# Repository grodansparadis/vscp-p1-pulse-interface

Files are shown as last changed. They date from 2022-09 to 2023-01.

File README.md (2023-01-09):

# vscp-p1-HAN-interface 

HAN P1 interface for smart meters to serial TTL. Should work with

| Meters |
| ------  |
| Sagemcom T211 / Ellevio & Skånska Energi |
| Landis+Gyr E360 |
| Itron A300 / Borås Elnät |
| S34U18 (Sanxing SX631) / Vattenfall |
| KAIFA MA304H4**E** / Nacka Energi (Not **D** version which is modbus) |
| KAIFA CL109 / Öresundskraft |
| Kamstrup w/ HAN module / Trollhättan Energi |
| and more. |

There is a description [here](https://grodansparadis.com/wordpress/?p=5039) about my setup. 

The PCB, [assembled](https://frogshop.se/product/kort-for-han-p1-ttl-serieinterface-monterat/?v=f003c44deab6) or [bare](https://frogshop.se/product/kort-for-han-p1-ttl-serieinterface-omonterat/?v=f003c44deab6), can be bought from https://frogshop.se/  

Bare PCB or mounted PCB is available from THE VSCP shop.

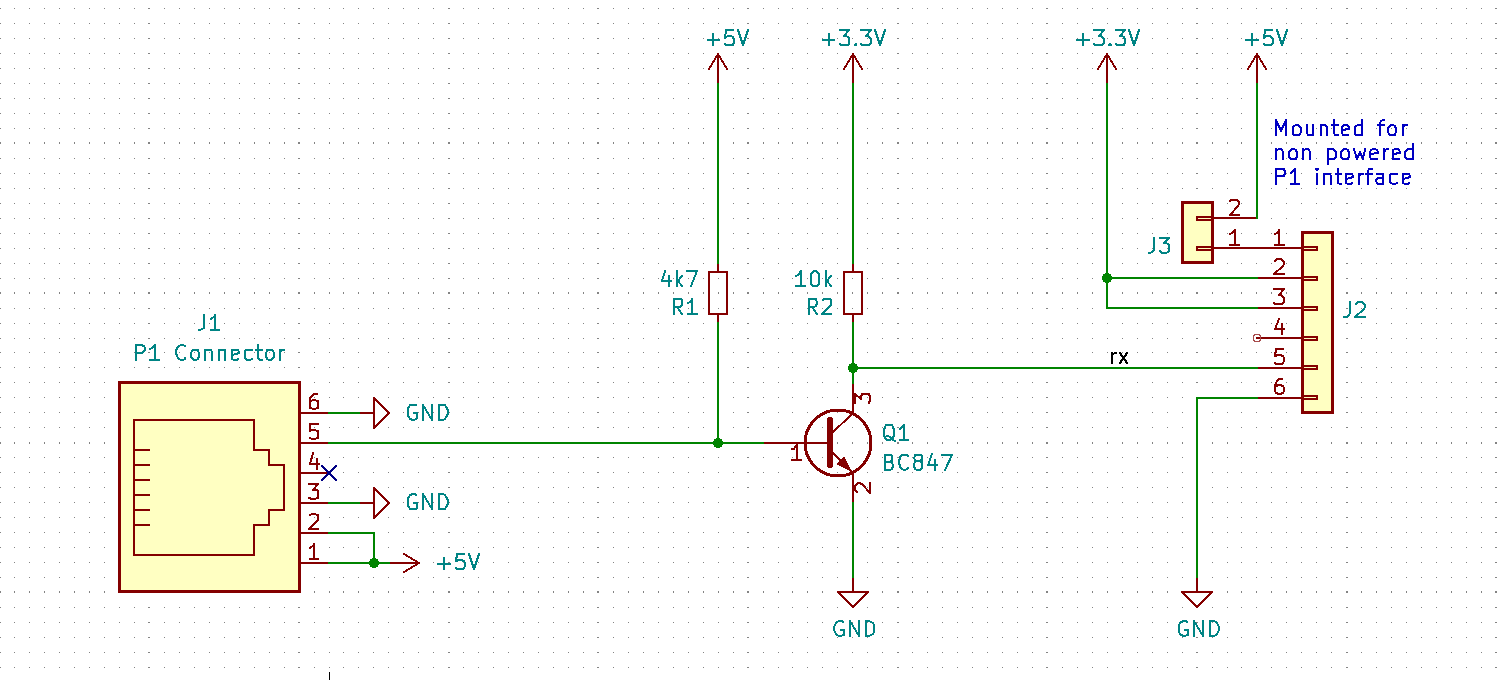
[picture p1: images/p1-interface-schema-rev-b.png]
Schema rev A


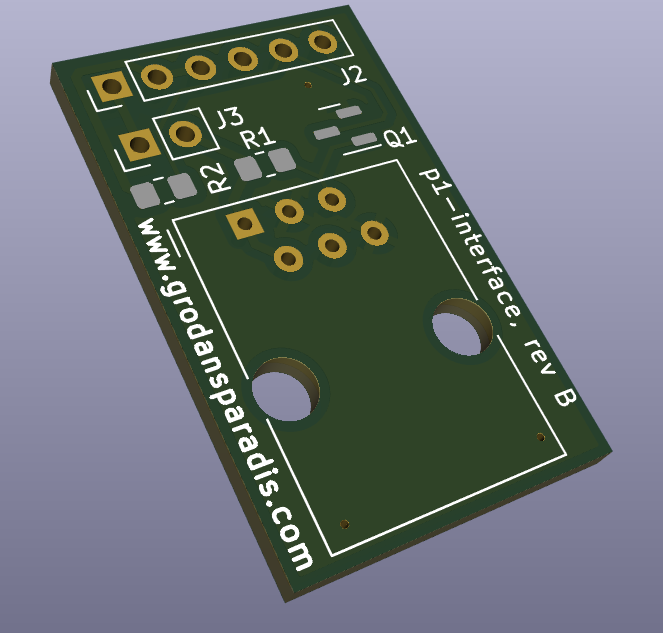
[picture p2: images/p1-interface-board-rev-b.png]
PCB P1 Interface card P1 Interface Card


Interface card for P1 based smartmeter to TTL serial interface.  

## BOM

| Component | Description |
| --- | --- |
| R1 | Resistor 4.7K 0805 |
| R2 | Resistor 10K 0805 |
| T1 | NPM Transistor BC847 |
| J1 | RJ11 Modular connector (Amphenol 54601 or similar) |
| J2 | 6-pin pinheader 2.54 pitch |
| J3 | 2-pin pinheader 2.54 pitch |

## J3 

Strap pins t use if the HAN interface does not provide power by itself.

## J2 Connections

| Pin | Description |
| --- | --- |
| 1 | +5V |
| 2 | +3.3V or 5V * |
| 3 | +3.3V or 5V * |
| 4 | Not Connected |
| 5 | RX (Received data TTL level) |
| 6 | GND |

* Use same power on 2/3 as the serial interface the unit is connected to.

## Connecting 

To connect the interface to a HAN P1 port a serial TTL interface is needed. We describe using an [USB to serial adapter](https://frogshop.se/product/usb-ttl-serial-adapter/?v=f003c44deab6) here but an Arduino or ESP8266/32 or similar can also be used.

First connect the interface to the serial adapter

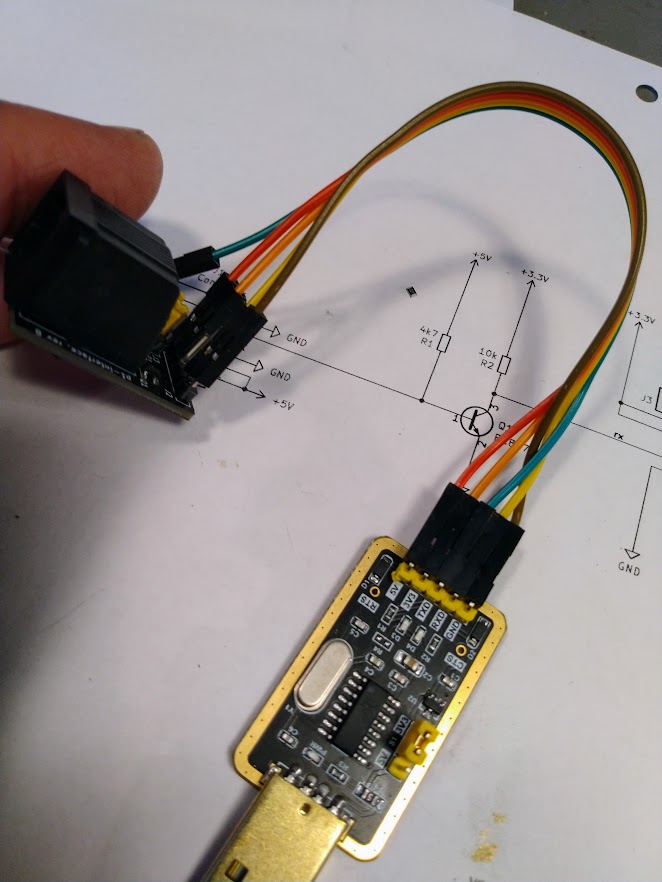
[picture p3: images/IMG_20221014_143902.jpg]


| Interface | TTL adapter |
| --- | --- |
| 1 | +5V |
| 2 | 3.3V |
| 3 | Not connected or 3.3V |
| 4 | Mot connected |
| 5 | RX |
| 6 | GND |

The following two pictures mau be clearer

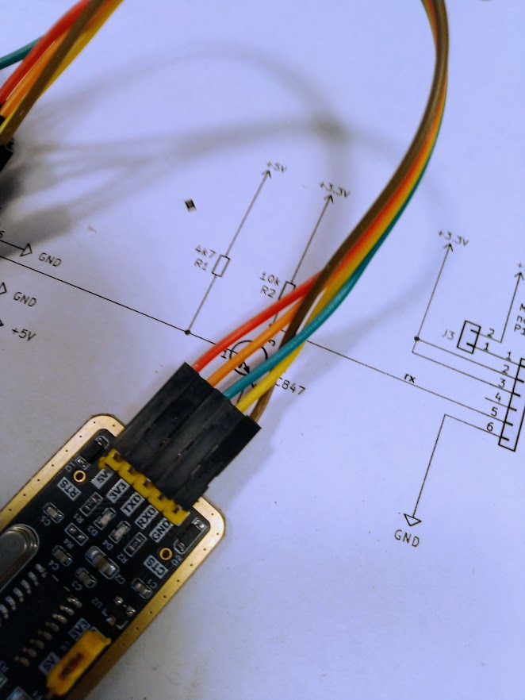
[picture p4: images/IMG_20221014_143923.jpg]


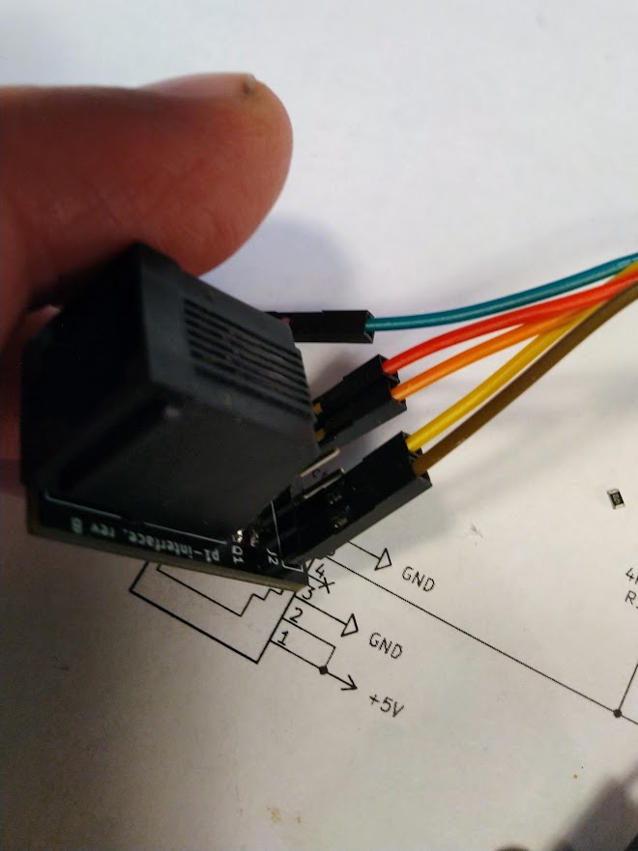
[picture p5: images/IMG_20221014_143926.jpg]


Now draw a standard six leads RJ12 cable from the HAN port of the meter and connect it to the interface. 

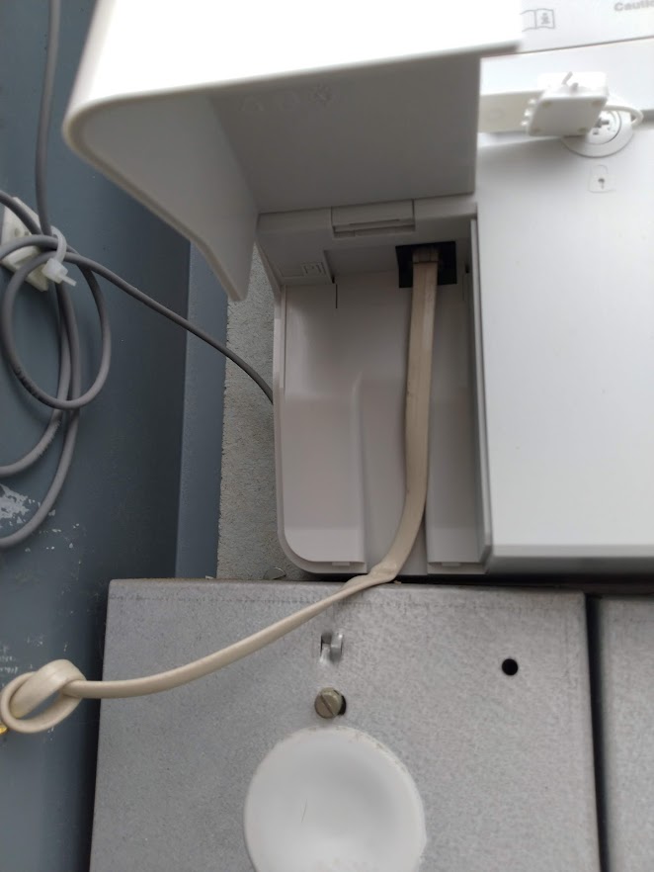
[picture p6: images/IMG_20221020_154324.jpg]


The cable should have the same colors on both connectors (straight cable). Like this

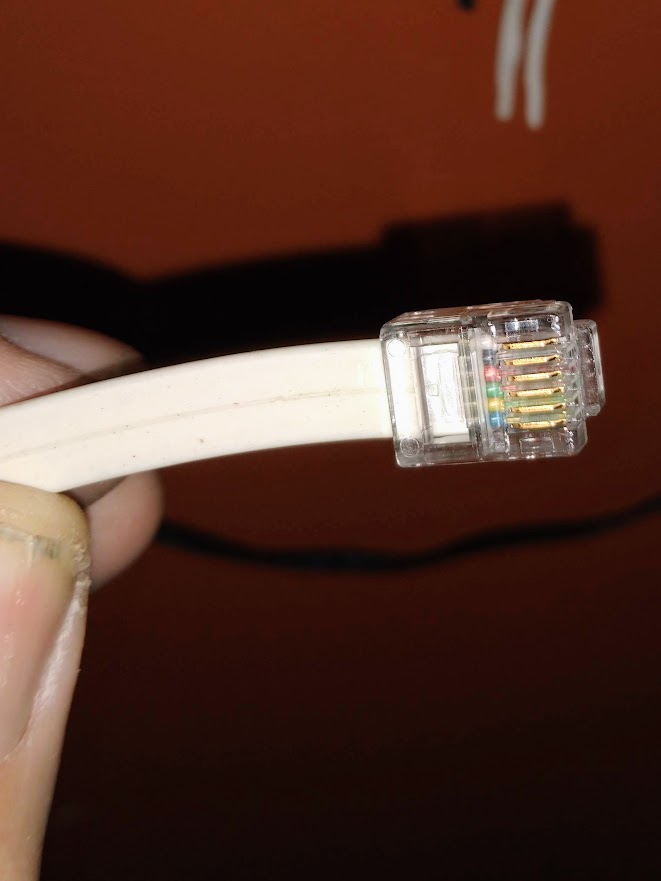
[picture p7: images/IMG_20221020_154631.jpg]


It is OK to use a cable of a few meters. At least if you are in an environment without to much electric disturbance.

Now connect the TTL USB adapter to the serial port. The blue LED should light up on the USB TTL serial adapter. 

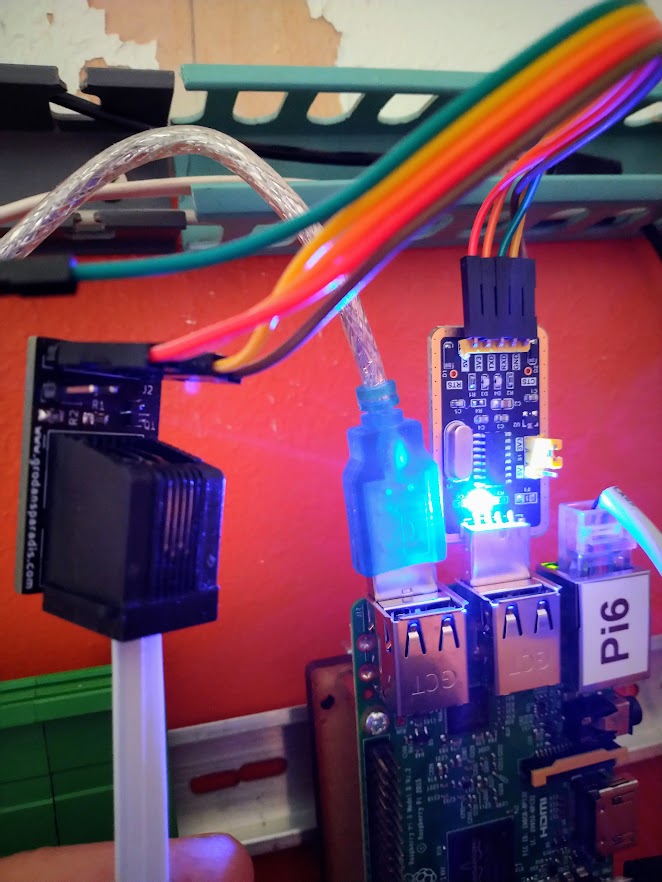
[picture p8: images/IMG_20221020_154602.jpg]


If everything is correct the red RX LED will light up every ten seconds to show that data is received.

Now you are ready to go. More info is [here](https://grodansparadis.com/wordpress/?p=5039) on how to proceed.

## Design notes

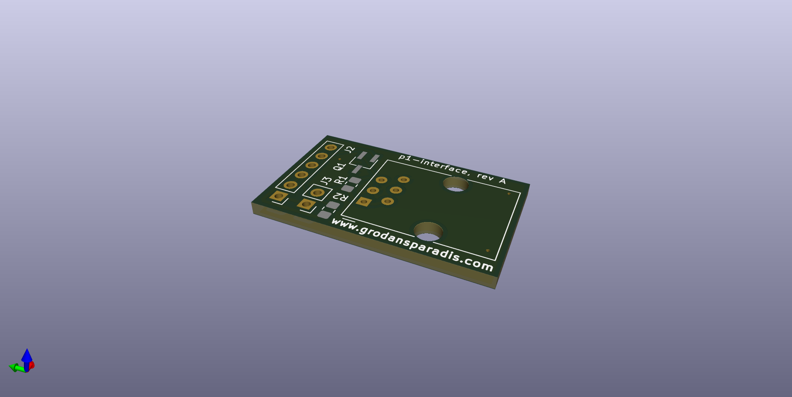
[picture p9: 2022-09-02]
images/p1-interface.png

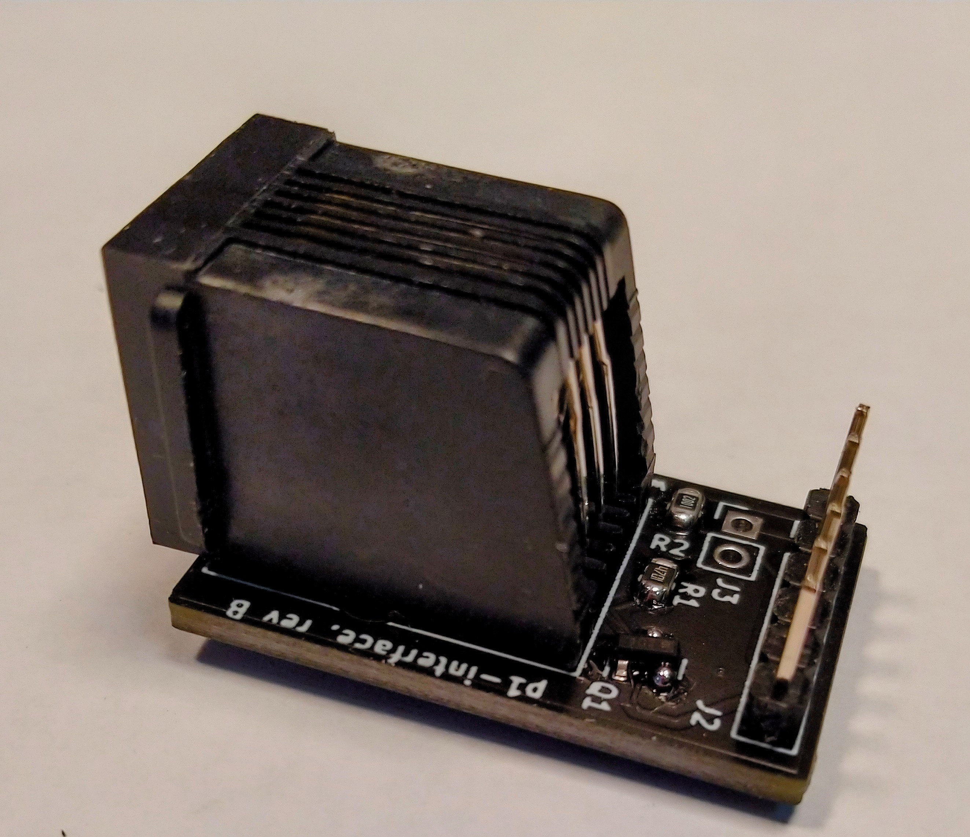
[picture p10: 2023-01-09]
images/IMG_20221020_165559~2.jpg

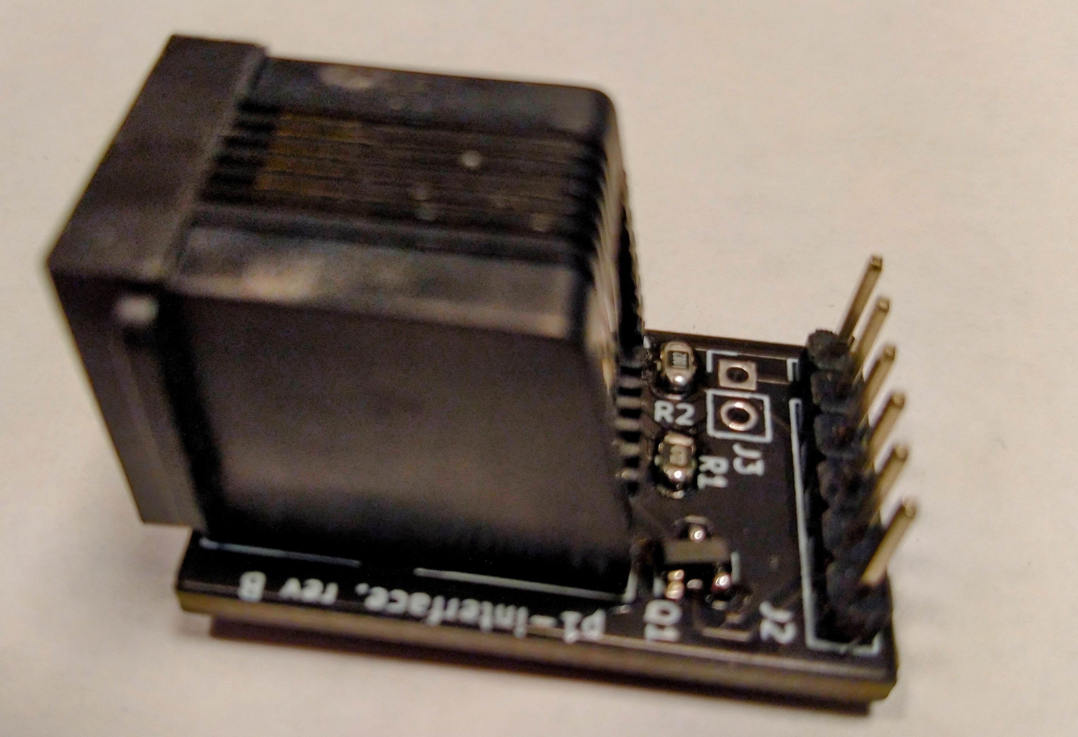
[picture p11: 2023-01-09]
images/IMG_20221020_172505~2.jpg

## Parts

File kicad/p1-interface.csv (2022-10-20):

Source: | /usr/local/src/VSCP/vscp-p1-pulse-interface/kicad/p1-interface.kicad_sch
Date: | fre 14 okt 2022 10:41:49
Tool: | Eeschema 6.0.7-f9a2dced07~116~ubuntu22.04.1
Generator: | /usr/share/kicad/plugins/bom_csv_grouped_by_value_with_fp.py
Component Count: | 6
Ref | Qnty | Value | Cmp name | Footprint | Description | Vendor
J1, | 1 | P1 Connector | 6P6C | Connector_RJ:RJ12_Amphenol_54601 | RJ connector, 6P6C (6 positions 6 connected), RJ12/RJ18/RJ25
J2, | 1 | Conn_01x06 | Conn_01x06 | Connector_PinHeader_2.54mm:PinHeader_1x06_P2.54mm_Vertical | Generic connector, single row, 01x06, script generated (kicad-library-utils/schlib/autogen/connector/)
J3, | 1 | Conn_01x02 | Conn_01x02 | Connector_PinHeader_2.54mm:PinHeader_1x02_P2.54mm_Vertical | Generic connector, single row, 01x02, script generated (kicad-library-utils/schlib/autogen/connector/)
Q1, | 1 | BC847 | BC847 | Package_TO_SOT_SMD:SOT-23 | 0.1A Ic, 45V Vce, NPN Transistor, SOT-23
R1, | 1 | 4k7 | R_Small | Resistor_SMD:R_0805_2012Metric_Pad1.20x1.40mm_HandSolder | Resistor, small symbol
R2, | 1 | 10k | R_Small | Resistor_SMD:R_0805_2012Metric_Pad1.20x1.40mm_HandSolder | Resistor, small symbol

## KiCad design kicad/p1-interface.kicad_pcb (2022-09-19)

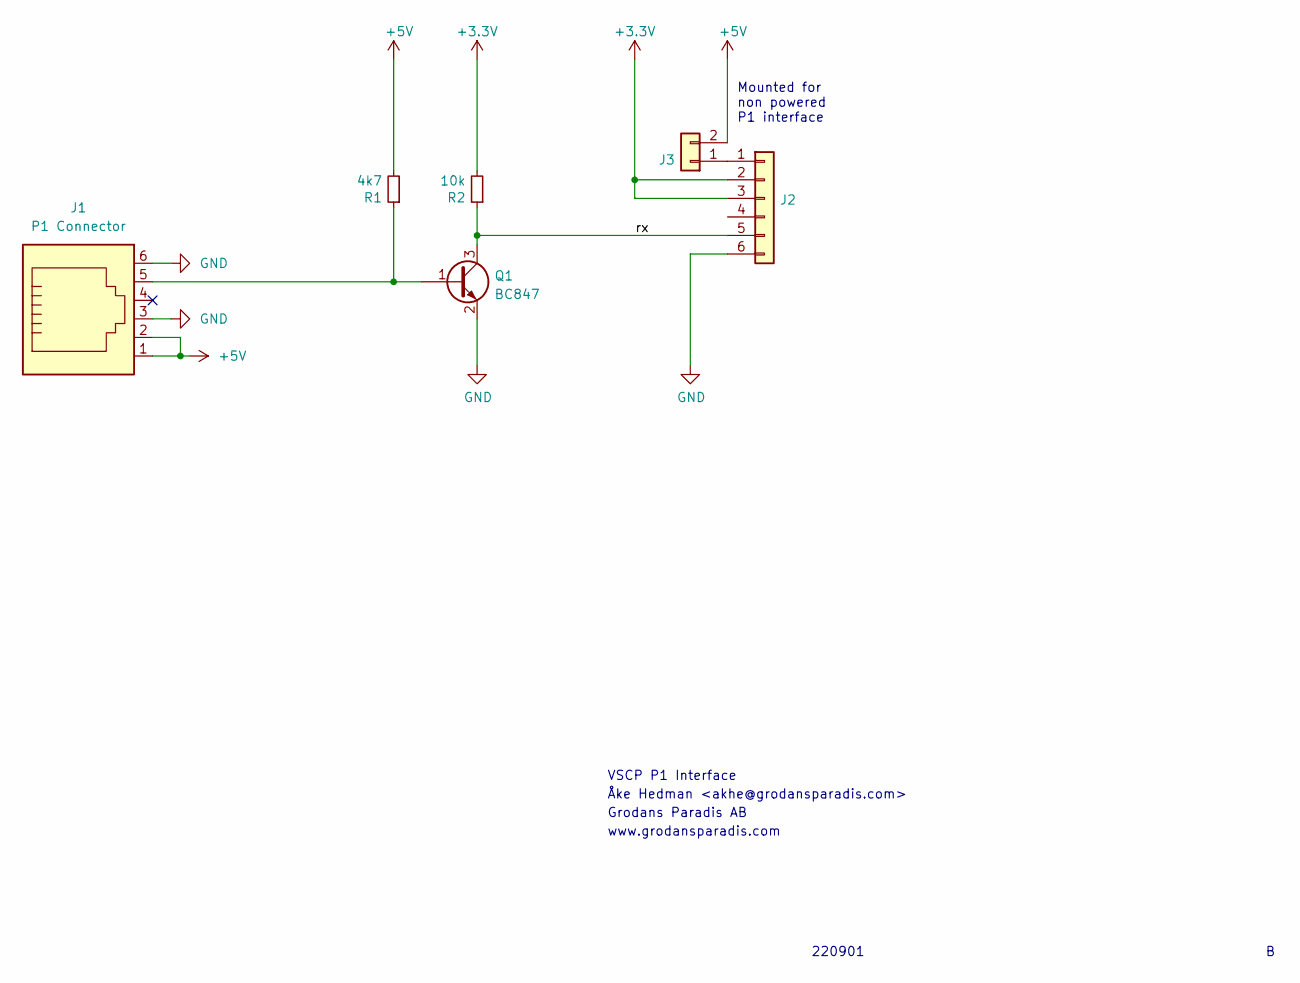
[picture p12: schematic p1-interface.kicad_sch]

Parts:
J1: P1 Connector; RJ12_Amphenol_54601
J2: Conn_01x06; PinHeader_1x06_P2.54mm_Vertical
J3: Conn_01x02; PinHeader_1x02_P2.54mm_Vertical
Q1: BC847; SOT-23
R1: 4k7; R_0805_2012Metric_Pad1.20x1.40mm_HandSolder
R2: 10k; R_0805_2012Metric_Pad1.20x1.40mm_HandSolder

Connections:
+3V3: J2.2, J2.3, R2.2
+5V: J1.1, J1.2, J3.2, R1.2
/rx: J2.5, Q1.3 (C), R2.1
GND: J1.3, J1.6, J2.6, Q1.2 (E)
unnamed: J1.5, Q1.1 (B), R1.1
unnamed: J2.1, J3.1

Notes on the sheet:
Mounted for non powered P1 interface
VSCP P1 Interface
Åke Hedman <akhe@grodansparadis.com>
www.grodansparadis.com
Grodans Paradis AB
220901

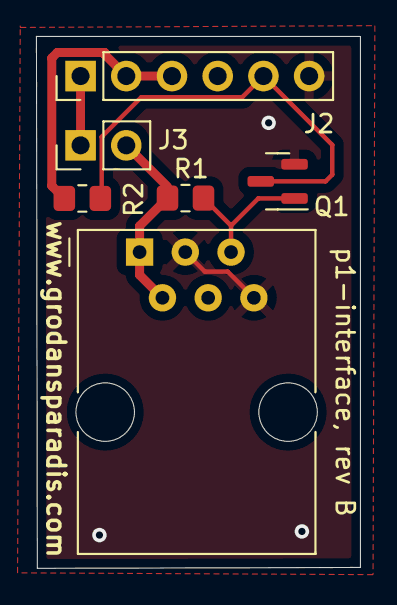
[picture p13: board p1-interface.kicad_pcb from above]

Board: 2 copper layers, 18.0 x 29.5 mm, 6 parts (0 on the bottom side), 6 nets.

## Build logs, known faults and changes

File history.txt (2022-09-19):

HISTORY
-------

220919 - Rev B
220919 - Q1 had wrong pinning.

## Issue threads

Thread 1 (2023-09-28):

ESP32 and vscp-p1-pulse-interface

kirilldem, 2023-09-28:
Hello,

I wonder if you can help me to connect your P1 port reader to the Omnia e-meter and lilygo T8 C3 ESP32 board.

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

I looked at the GitHub instructions and still not sure how it should be connected, maybe you can share your thoughts on my reasoning below:

1	+5V - **5V on the ESP32 Board**
2	+3.3V or **5V * - Not connecting?**
3	+3.3V or **5V *  - Not connecting?**
4	Not Connected
5	RX (Received data TTL level) - **GPIO09 as per my software (AMS2MQTT)**
6	GND - **GND**

grodansparadis, 2023-09-28:
I responded to your mail wit this answere. Is it unclear? If so please aks again.

If you connect the card to the meter and install jumper J3 you will have +5V to power to the EPS32 board on pin 1 of the interface.  But as the ESP32 inputs are 3V you need to connect 3.3V to one of pin2/3 or both. Now connect pin 5 to your rx and connect ground together.

ESP32  -  Interface
===========
+5V    -  pin 1
+3.3V -  pin 2/3
GND    -  pin 6
RX       -  pin 5

Baudrate 115200. Non inverting.

You have 250 mA you can use form the +5V on the meter.  Wifi can give peaks that are above this so a large capacitor 1000uF or bigger on +5V is good. You can power the ESP32 module externally of course and then leave the J3 open and do not connect +5V to pin 1.

kirilldem, 2023-09-28:
Thanks for the response - I did not receive your response, just checked my spam and nothing there either - so I thought perhaps github is a better place to ask :)

The explanation makes sense, except J3 jumper, do you mean these?

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

Should I put one of these on the J3 jumper?

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

grodansparadis, 2023-09-28:
Strange that you did not recveive it. It was sen 16:41 the same day you wrote.   Anyway Github is better in case someone else have the same questions

Put in the jumper if you intend to power everything from the meter. Then you will get +5V on pin 1.  If it's there all positions marked +5V will be connected together. If you intend to power your board from USB or by other means don't put the jumper in. Connect +5V instead to pin 1.

kirilldem, 2023-10-16:
Hi again, thanks for the clarification and sorry for the delay in getting back to you. I am still trying to figure this out.

I intend to power the board from the meter, I checked with the multi meter and I get 5v on pin 1 with the jumper (good that I also got the serial connector from you as that one had one spare :) ) I get no voltage on pin 2 and 3 - I guess this is expected.

So here is my revision of it should all be connected:

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

Just not sure why 5V from pin 1 doesnt go to 5V on the ESP board and if I need pins 2 and 3 connected to the ESP board at all.

I'm quite new to this, so excuse me for maybe stupid questions :)

kirilldem, 2023-10-16:
> ## With the jumper installed
> Pin 1 - should go to +5V on the ESP board! Connecting it to 3.3V will probably burn the ESP board. Pin 6 - GND should go to GND (any) on the ESP board. Pin 2/3 - One of 2/3 should go to +3.3V on the ESP32 board. Pin 5 - Should go to the RX input. Looks like this is GPIO20 on your board from the picture.

That has worked, thank you so much for your advice and patience.

grodansparadis, 2023-10-17:
No problem, happy to help.

Closed 2023-10-17.

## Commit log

2022-09-02 Initial checkin
    [p1-interface-B_Cu.gbr, p1-interface-B_Mask.gbr, p1-interface-B_Paste.gbr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]
2022-09-15 Added picture of schema
    [p1-interface.kicad_sch]
2022-09-19 Updated images and readme for rev B
    [p1-interface-B_Cu.gbr, p1-interface-B_Mask.gbr, p1-interface-B_Paste.gbr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]
2022-10-20 Added setup instructions
    [p1-interface.csv]
